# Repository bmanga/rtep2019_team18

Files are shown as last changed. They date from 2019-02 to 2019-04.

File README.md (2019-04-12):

# Gait Analysis and Interactive Training 

<p align="center">
	
</p>

### Overview
GAIT is about the development of a Raspberry Pi wearable system which analyses the user's walking characteristics and provides targeted training in two separate modes, namely Gait and Training mode.

In Gait mode, data is analysed and classified in real time by use of a deep convolutional neural network which automatically predicts the nature of the gait from the signals received from IMUs mounted on the lower limb and pressure sensors embedded in modified insoles. Training mode offers typical game-based rehabilitation exercises, including weight shifting and calf pushes, and provides both auditory and visual feedback to the user, with games being streamed to an external screen.

This device aims to promote neuroplasticity for motor rehabilitation of stroke patients and may therefore become an auxiliary tool in the recovery of motor functions of stroke survivors. 

Learn more about GAIT on the [Wiki](https://github.com/bmanga/rtep2019_team18/wiki). 

<p align="center">
	
</p>

### Prerequisites
* [conan](https://conan.io/) package manager - it can be installed by running ```pip install conan```
  * Make sure you have added the bincrafters remote repository. If not, run:<br/>
 ```conan remote add bincrafters https://api.bintray.com/conan/bincrafters/public-conan```
* [cmake](https://cmake.org/) build system version 3.8 or above

### Build Instructions
From within the cloned repository directory :
* ```mkdir build && cd build```
* ```conan install ..```
* ``` cmake ..```
* ```make```

Or use your favourite ```cmake``` configuration.

### Contributions Guidelines
All code is formatted through `clang-format` according to the `.clang-format` file. `clang-format-6.0` is the recommended version as that's the one used in CI.

The utility script `utils/format_diff_code.sh` (to be run from project root directory) is provided in order to automatically format the changes.

Alternatively, you can copy `utils/pre-commit` into the `.git/hooks` folder to automatically run `clang-format` on commits.

### Follow us!

* [Website](https://gaituofg.wixsite.com/website/)
* [Facebook](https://www.facebook.com/GaitUofG/?modal=admin_todo_tour/) 
* [Twitter](https://twitter.com/GaitUofG/) 
* [Instagram](https://www.instagram.com/gait_uofg/) 
* [YouTube](https://www.youtube.com/channel/UCVHNSSwxwb6042Gx61-woFg/)

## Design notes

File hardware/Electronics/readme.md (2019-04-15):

The Electronics folder contains the EAGLE files and data sheets for the IMU PCB and Raspberry Pi Integration Board. Each board is contained within its own folder which also contains images of the PCB's manufactured for our system.

The PCB schematic and EAGLE files conatained in this folder are as follows:
<dl>
  <b>IMU</b>
  <ul>
  <li>Board Schematic</li>
  <li>Board Layout</li>
</ul>
</dl>
<dl>
 <b>Integration Board</b>
  <ul>
  <li>Integration Board Schematic</li>
  <li>Integration Board Layout</li>
</ul>
</dl>

A description of each of these components and relative illustrations can be found in the [Wiki](https://github.com/bmanga/rtep2019_team18/wiki).

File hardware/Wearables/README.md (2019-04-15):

The Wearables folder contains the .stl files and technical drawings of the mechanical components of the device. The .stl format can be directly used for 3D printing and computer-aided manufacturing, while the technical drawings illustrate the dimensions of each part codified in ISO standards. These are grouped into two subfolders: IMU Case and RPI Box. 

A separate .stl file exists for every part component, while these are grouped together in the technical drawings. The components of the IMU Case and of the RPI box are as follows:

<dl>
  <b>IMU Case</b>
  <ul>
  <li>Top component</li>
  <li>Bottom component</li>
</ul>
</dl>
<dl>
 <b>RPI Box</b>
  <ul>
  <li>Base</li>
  <li>Cover</li>
  <li>Support</li>
  <li>Hook</li>
</ul>
</dl>

A description of each of these components and relative illustrations can be found in the [Wiki](https://github.com/bmanga/rtep2019_team18/wiki).

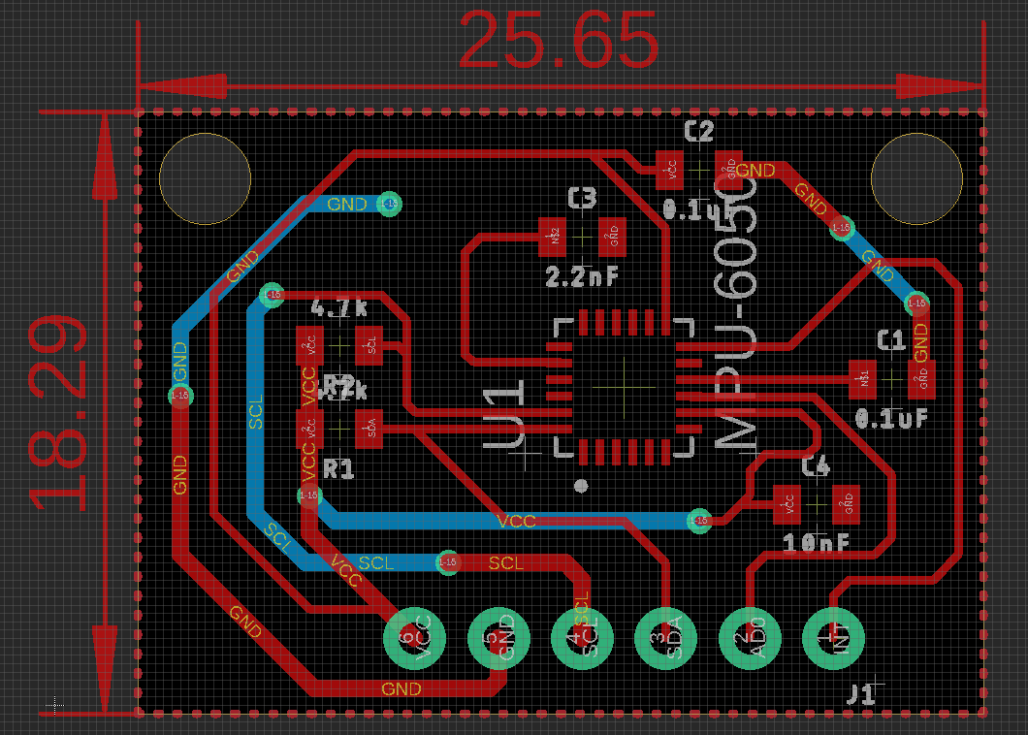
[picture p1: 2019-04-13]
hardware/Electronics/IMU/IMU Board Layout.PNG

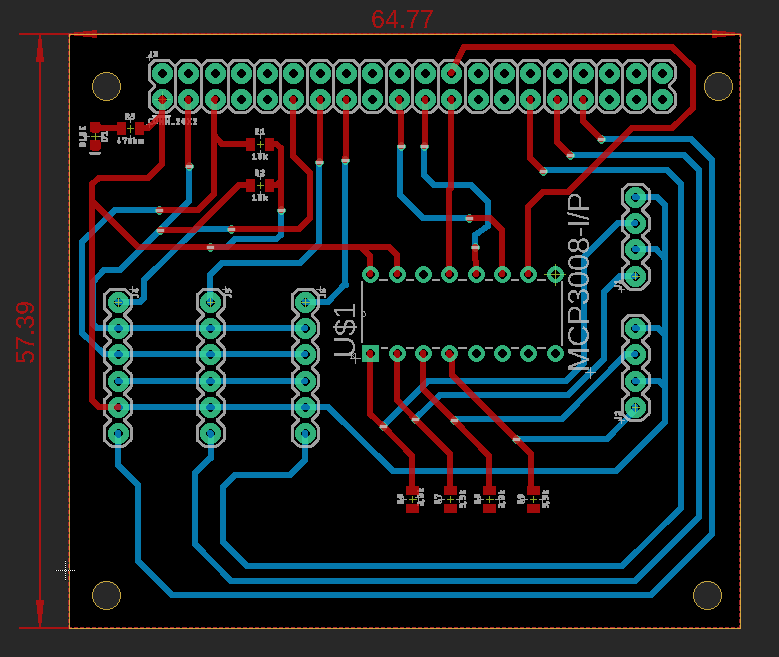
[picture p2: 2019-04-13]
hardware/Electronics/Integration Board/Eagle Files/Integration Board Layout.PNG

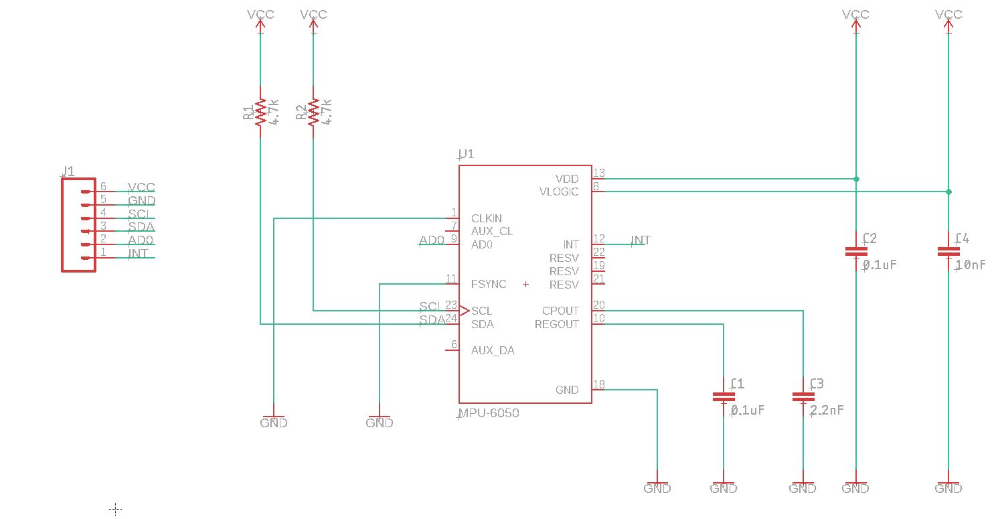
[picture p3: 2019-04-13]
hardware/Electronics/IMU/IMU Board Schematic.PNG

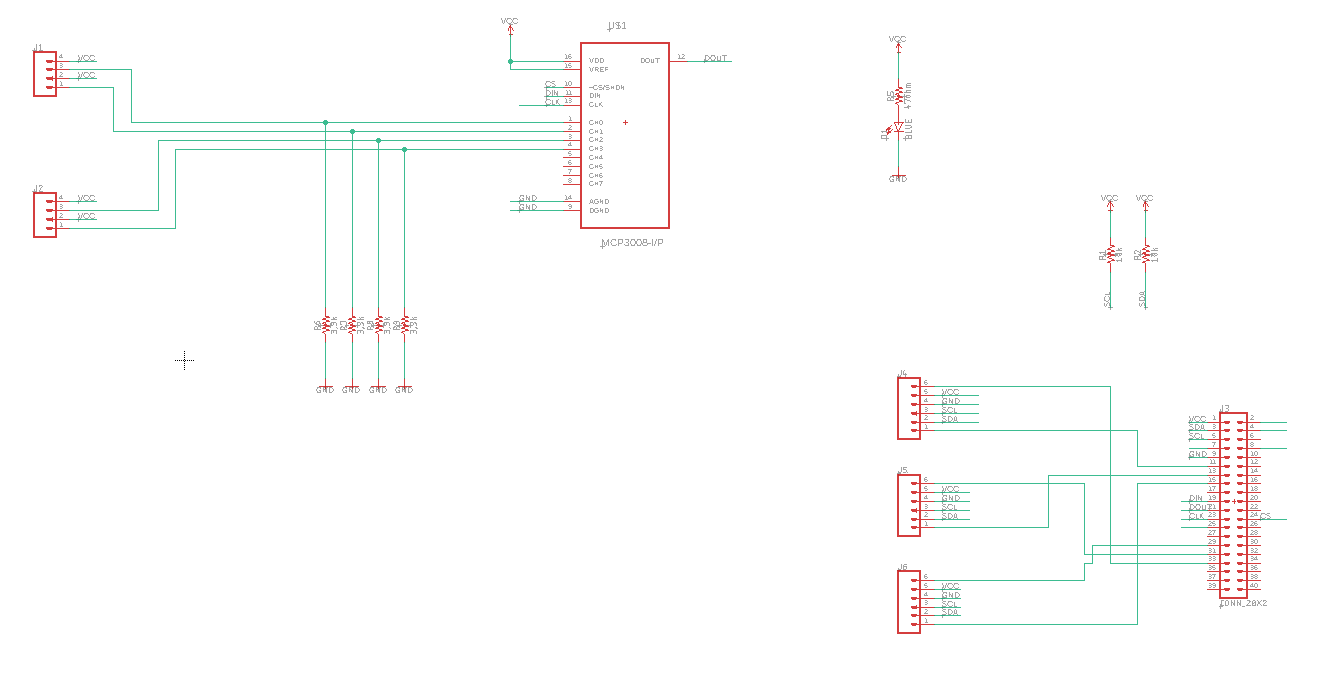
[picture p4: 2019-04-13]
hardware/Electronics/Integration Board/Eagle Files/Integration Board Schematic.PNG

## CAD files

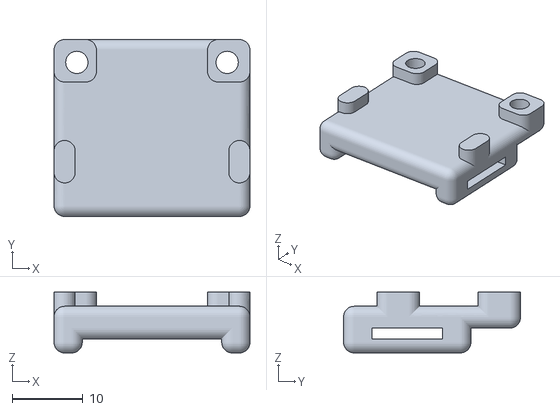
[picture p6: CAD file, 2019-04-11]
hardware/Wearables/IMU case/STL files/Bottom part.stl
27.7 x 25.0 x 8.60

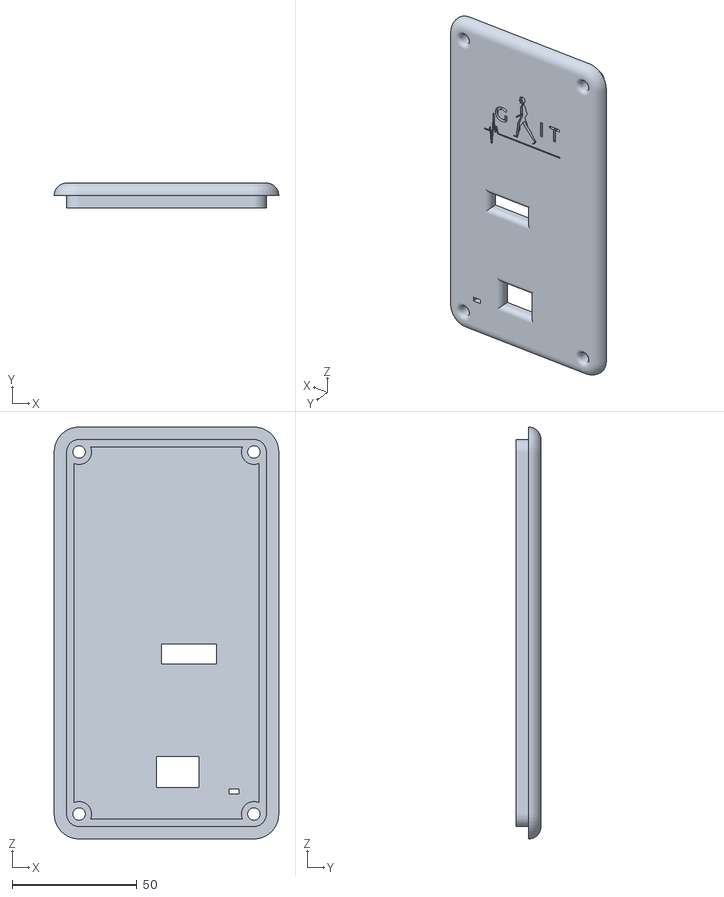
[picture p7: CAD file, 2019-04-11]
hardware/Wearables/RPI box/STL files/Top.STL
90.0 x 10.0 x 165.0

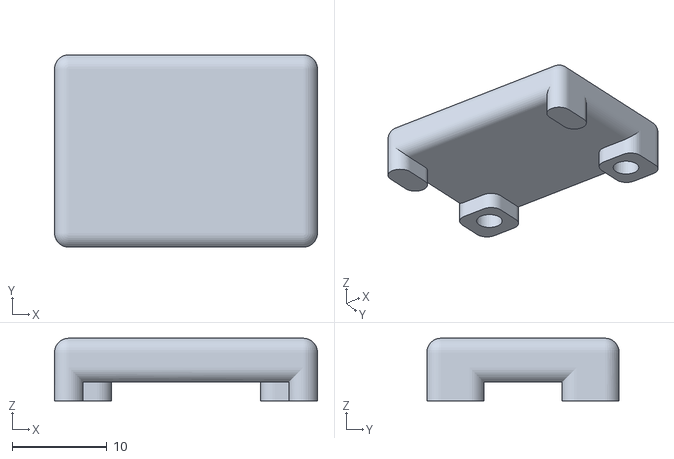
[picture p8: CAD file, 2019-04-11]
hardware/Wearables/IMU case/STL files/Top part.stl
27.7 x 20.3 x 6.60

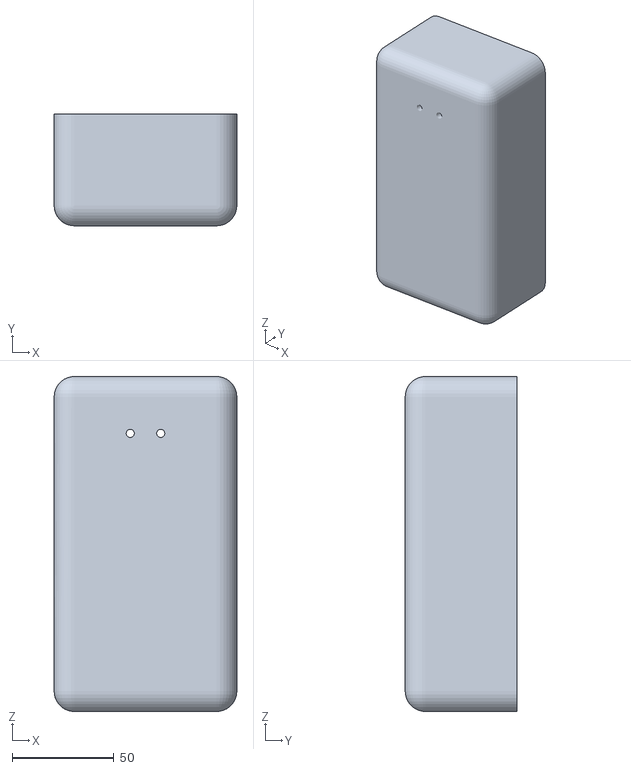
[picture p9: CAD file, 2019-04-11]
hardware/Wearables/RPI box/STL files/Base.STL
90.0 x 55.0 x 165.0

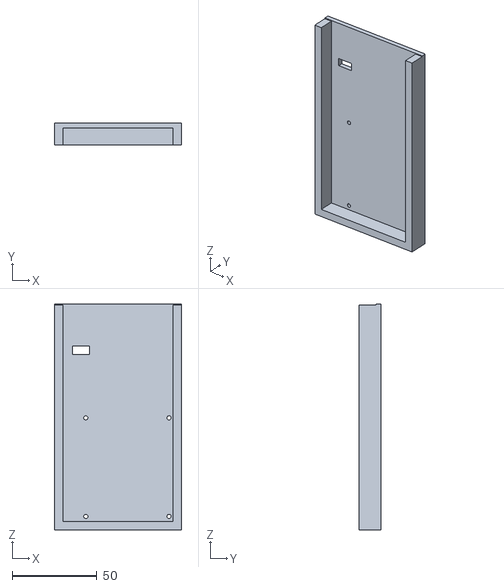
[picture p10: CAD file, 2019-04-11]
hardware/Wearables/RPI box/STL files/Middle.STL
75.0 x 13.0 x 133.0

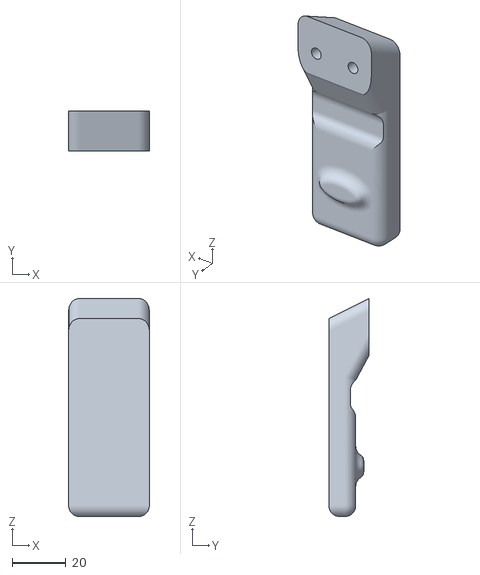
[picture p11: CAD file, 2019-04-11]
hardware/Wearables/RPI box/STL files/Hook.STL
30.0 x 15.0 x 81.1

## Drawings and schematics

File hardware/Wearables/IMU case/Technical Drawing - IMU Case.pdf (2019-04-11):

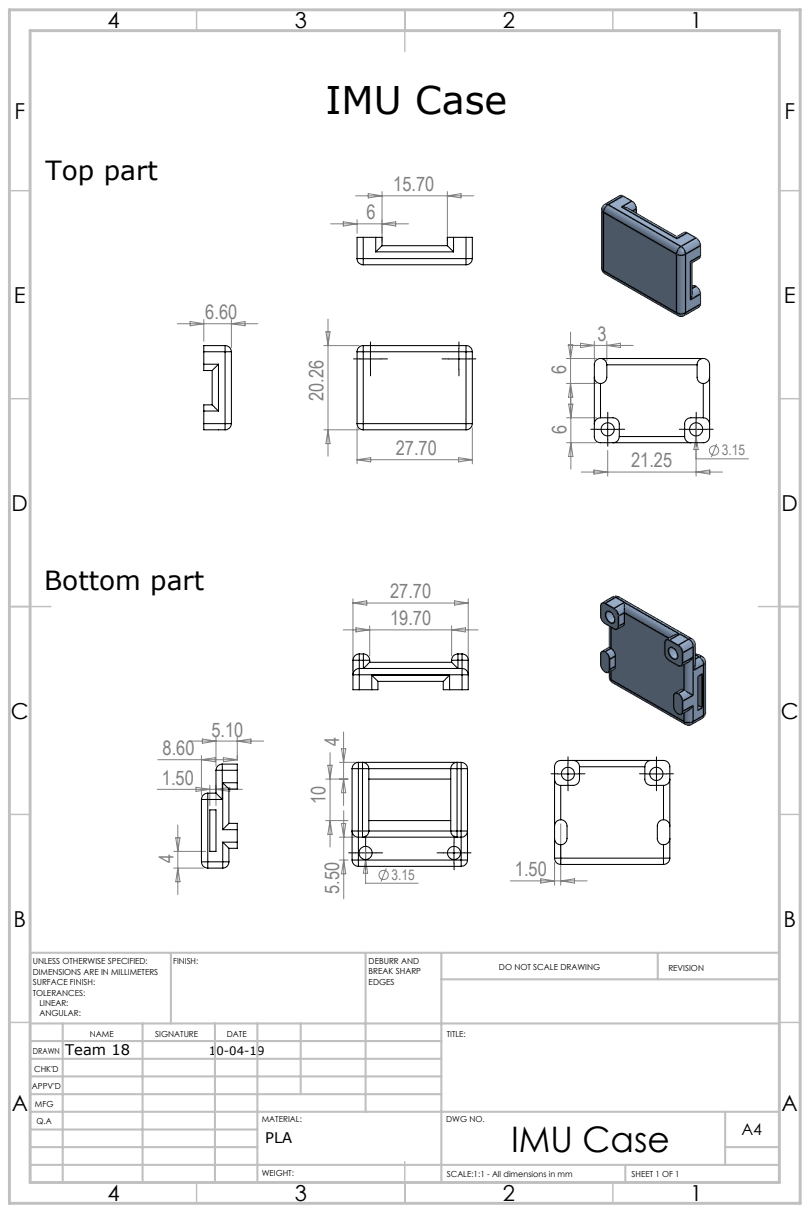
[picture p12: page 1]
IMU Case; Bottom part; Top part; FINISH:; DEBURR AND; BREAK SHARP; DO NOT SCALE DRAWING; REVISION; SCALE:1:1 - All dimensions in mm; SHEET 1 OF 1

UNLESS OTHERWISE SPECIFIED:
DIMENSIONS ARE IN MILLIMETERS
SURFACE FINISH:
TOLERANCES:
LINEAR:
ANGULAR:

NAME | SIGNATURE | DATE | | | | TITLE:

DRAWN | Team 18 | 10-04-19

CHK'D
APPV'D
MFG
Q.A | | | | MATERIAL: PLA | DWG NO. IMU Case | A4

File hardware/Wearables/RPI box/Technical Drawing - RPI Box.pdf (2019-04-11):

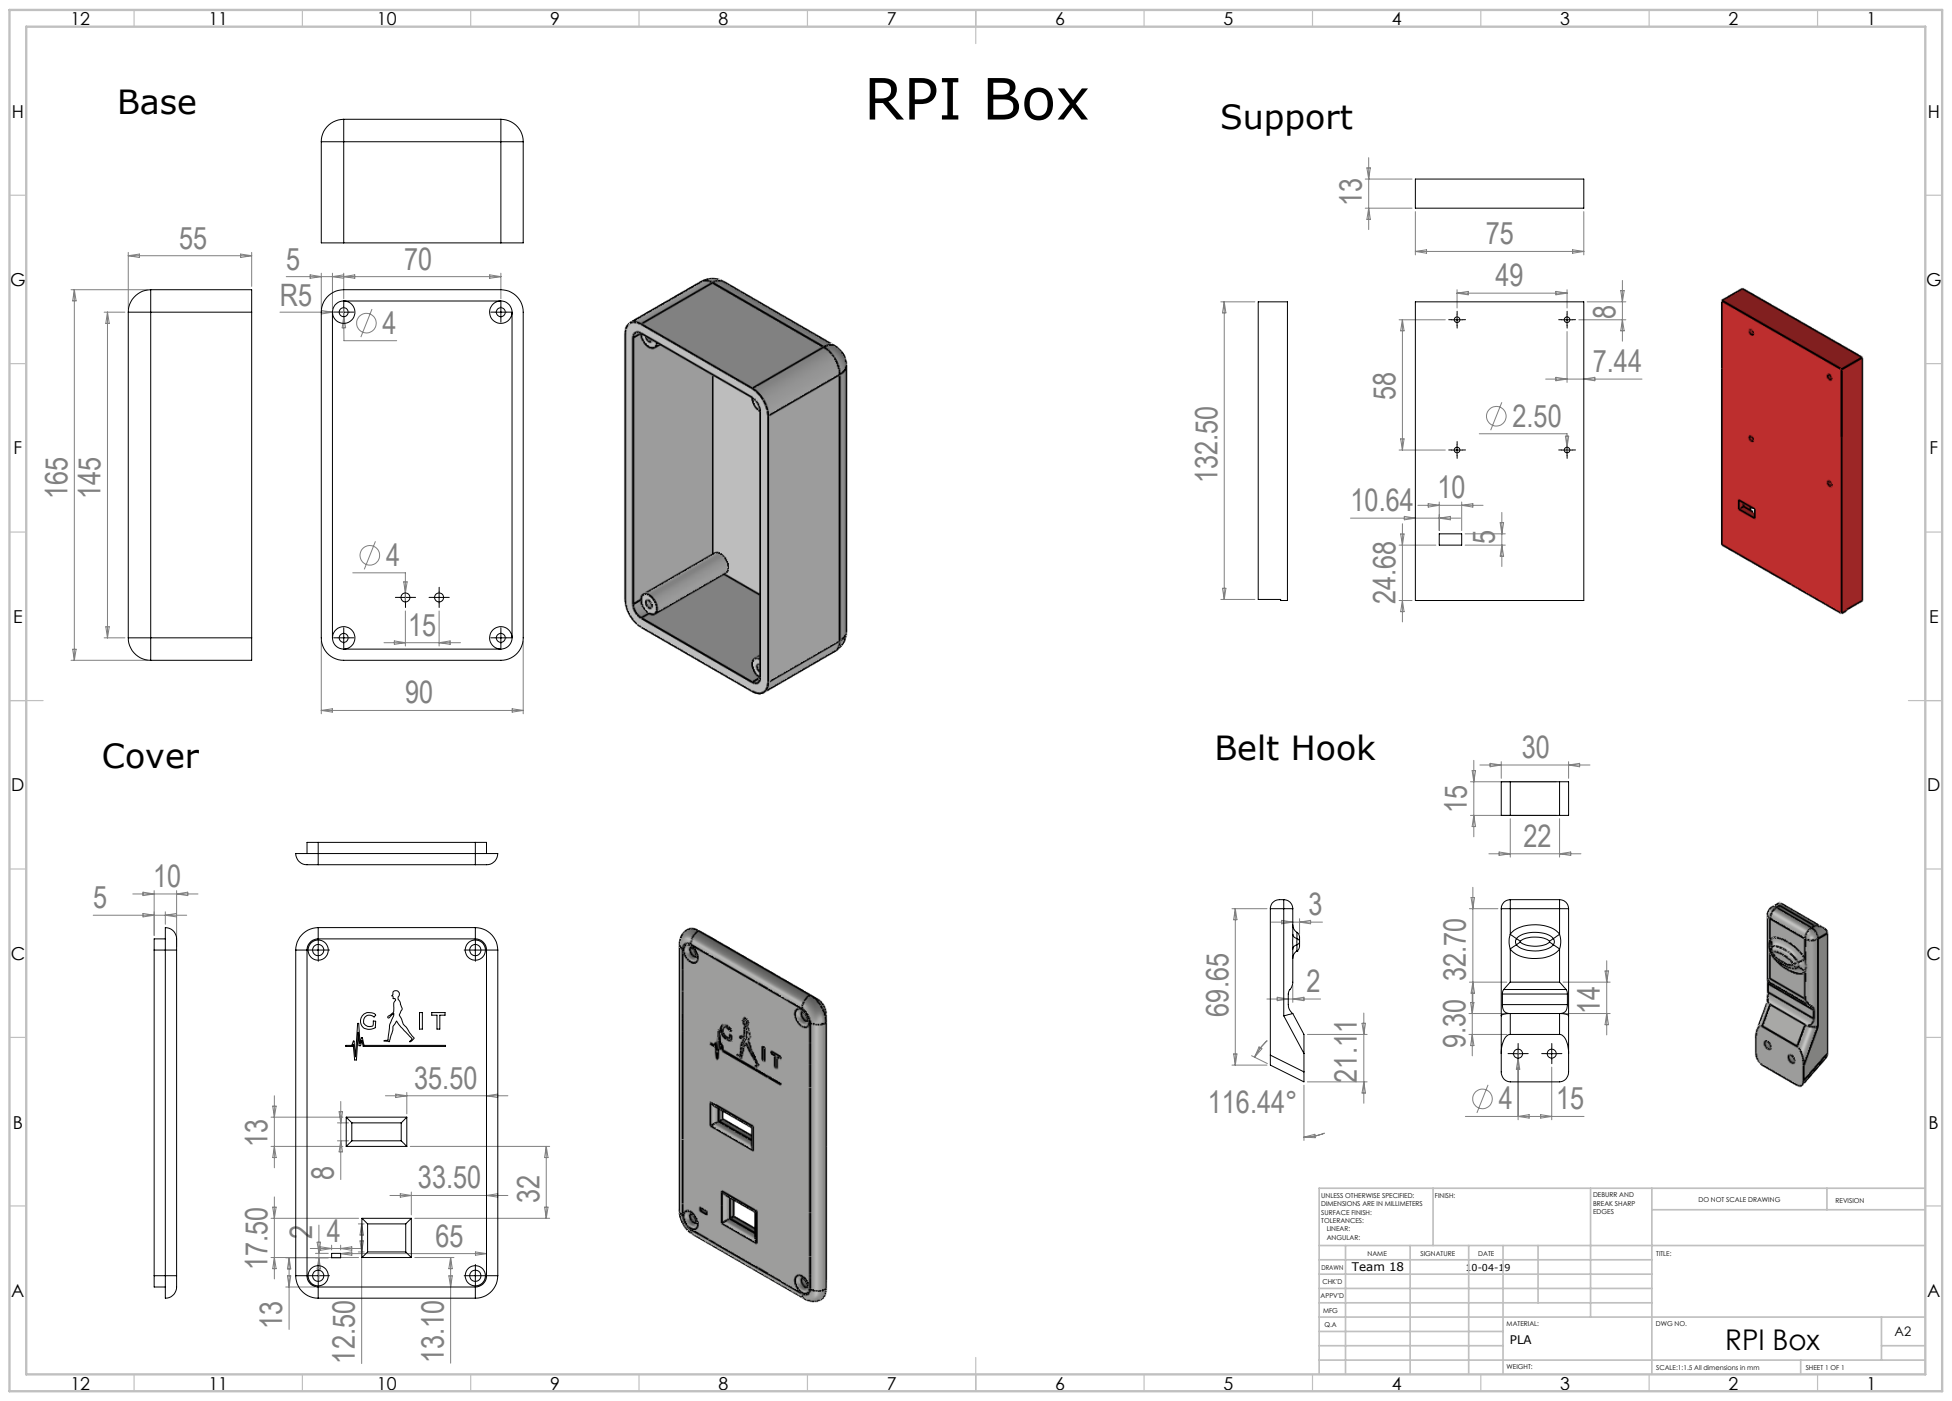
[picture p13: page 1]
Base; RPI Box; Support; Cover; Belt Hook; SCALE:1:1.5 All dimensions in mm; SHEET 1 OF 1

UNLESS OTHERWISE SPECIFIED: DIMENSIONS ARE IN MILLIMETERS SURFACE FINISH: TOLERANCES: LINEAR: ANGULAR: | FINISH: | DEBURR AND BREAK SHARP EDGES | DO NOT SCALE DRAWING | REVISION

NAME | SIGNATURE | DATE | | | | TITLE:

DRAWN | Team 18 | 10-04-19

CHK'D
APPV'D
MFG
Q.A | | | | MATERIAL: PLA | DWG NO. RPI Box | A2

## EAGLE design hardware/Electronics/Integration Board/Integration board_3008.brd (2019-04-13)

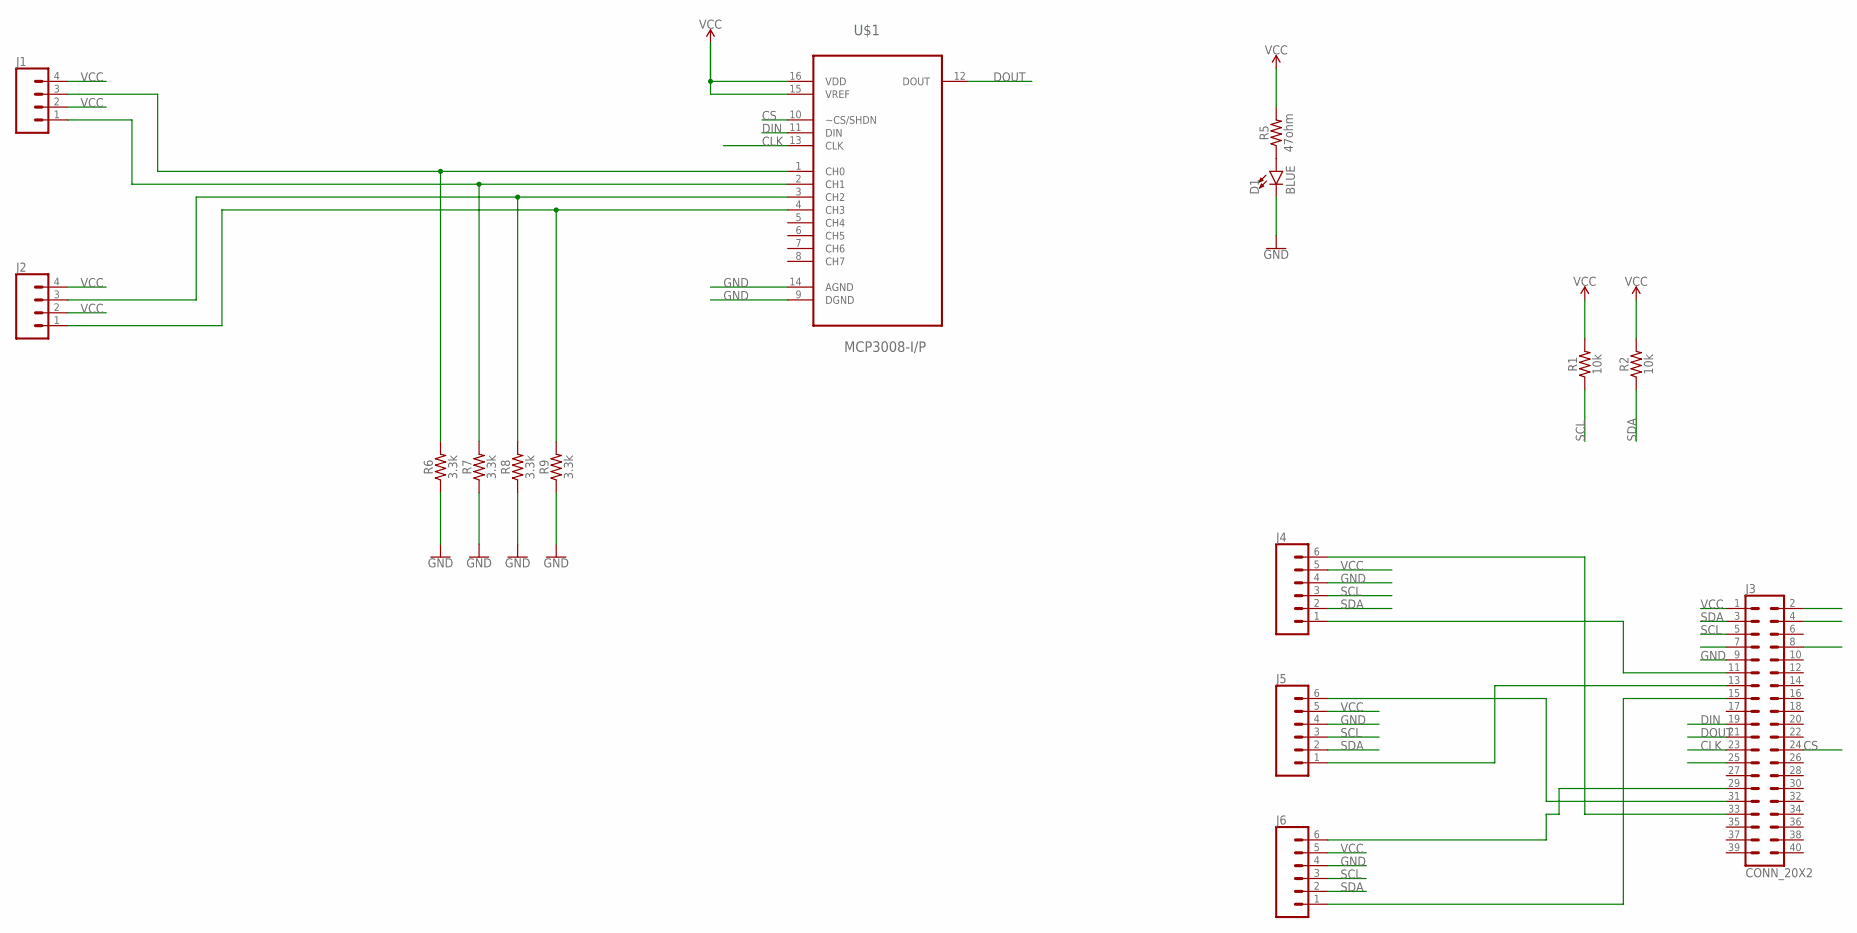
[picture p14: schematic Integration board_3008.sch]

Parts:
D1: BLUE; LED-0603
J1, J2: CONN_04PTH; 1X04
J3: CONN_20X2; 2X20
J4, J5, J6: CONN_06SILK_FEMALE_PTH; 1X06
R1, R2: 10k; 0805
R5: 47ohm; 0805
R6, R7, R8, R9: 3.3k; 0805
U$1: MCP3008-I/P; DIP254P762X432-16

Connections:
CLK: J3.23, U$1.13 (CLK)
CS: J3.24, U$1.10 (~CS/SHDN)
DIN: J3.19, U$1.11 (DIN)
DOUT: J3.21, U$1.12 (DOUT)
GND: D1.C, J3.9, J4.4, J5.4, J6.4, R6.1, R7.1, R8.1, R9.1, U$1.9 (DGND), U$1.14 (AGND)
unnamed: J1.3, R6.2, U$1.1 (CH0)
unnamed: J3.11, J4.1
unnamed: J2.3, R8.2, U$1.3 (CH2)
unnamed: J2.1, R9.2, U$1.4 (CH3)
unnamed: J3.13, J5.1
unnamed: J3.29, J6.6
unnamed: J3.31, J5.6
unnamed: D1.A, R5.1
unnamed: J1.1, R7.2, U$1.2 (CH1)
unnamed: J3.33, J4.6
unnamed: J3.15, J6.1
SCL: J3.5, J4.3, J5.3, J6.3, R1.1
SDA: J3.3, J4.2, J5.2, J6.2, R2.1
VCC: J1.2, J1.4, J2.2, J2.4, J3.1, J4.5, J5.5, J6.5, R1.2, R2.2, R5.2, U$1.15 (VREF), U$1.16 (VDD)

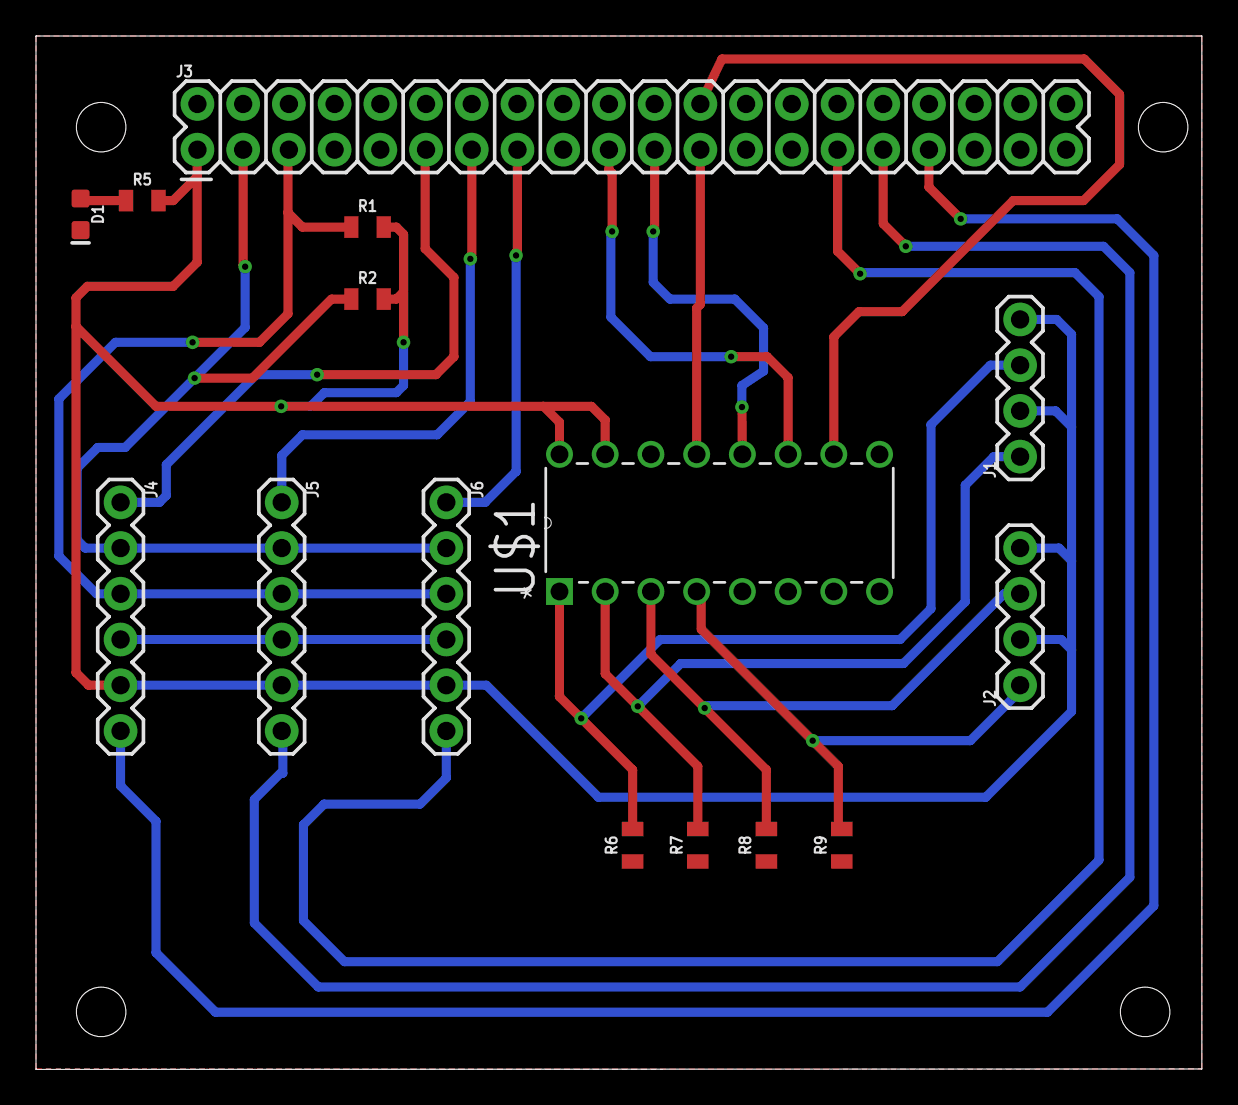
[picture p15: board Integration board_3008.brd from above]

Board: 2 copper layers, 64.8 x 57.4 mm, 15 parts (0 on the bottom side), 19 nets.

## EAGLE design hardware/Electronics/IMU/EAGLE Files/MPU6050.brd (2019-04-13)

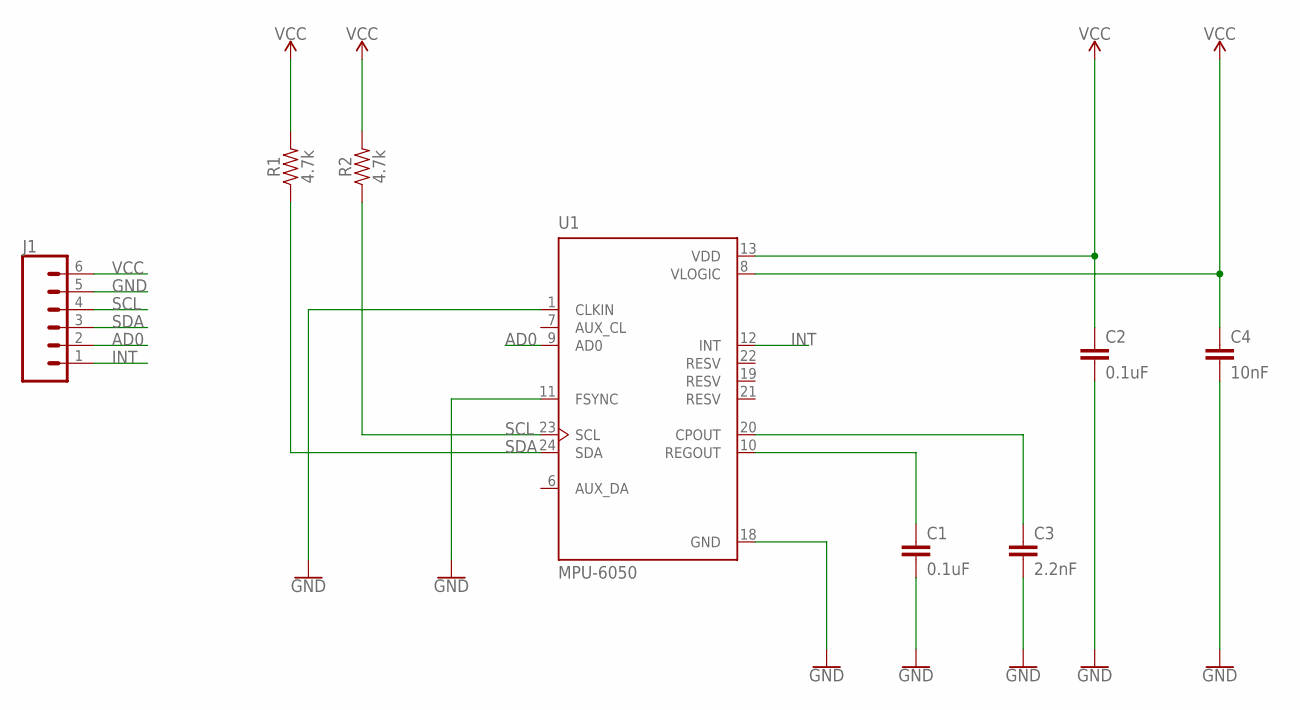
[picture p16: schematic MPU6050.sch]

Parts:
C1, C2: 0.1uF; 0805
C3: 2.2nF; 0805
C4: 10nF; 0805
J1: CONN_06NO_SILK_FEMALE_PTH; 1X06_NO_SILK
R1, R2: 4.7k; 0805
U1: MPU-6050; QFN50P400X400X95-24N

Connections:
AD0: J1.2, U1.9 (AD0)
GND: C1.2, C2.2, C3.2, C4.2, J1.5, U1.1 (CLKIN), U1.11 (FSYNC), U1.18 (GND)
INT: J1.1, U1.12 (INT)
unnamed: C1.1, U1.10 (REGOUT)
unnamed: C3.1, U1.20 (CPOUT)
SCL: J1.4, R2.1, U1.23 (SCL)
SDA: J1.3, R1.1, U1.24 (SDA)
VCC: C2.1, C4.1, J1.6, R1.2, R2.2, U1.8 (VLOGIC), U1.13 (VDD)

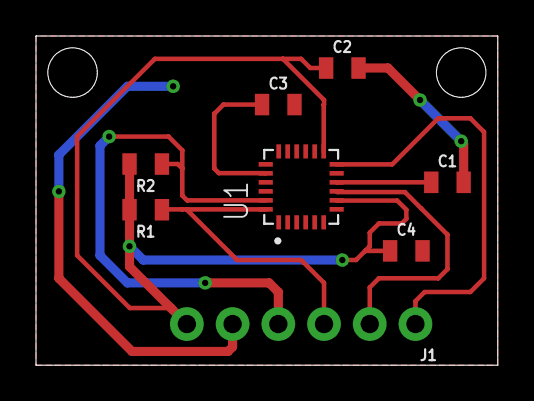
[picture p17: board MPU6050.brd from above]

Board: 2 copper layers, 25.7 x 18.3 mm, 8 parts (0 on the bottom side), 8 nets.

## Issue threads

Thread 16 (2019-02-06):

Vibrating motor evaluation

lucaros95, 2019-02-06:

bmanga, 2019-04-01:
No longer required: we don't use the motors as feedback anymore.

Closed 2019-04-01.

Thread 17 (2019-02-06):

Create the prototype shoe

lucaros95, 2019-02-06:

lucaros95, 2019-03-06:
Force distribution to avoid saturation achieved

Closed 2019-04-01.

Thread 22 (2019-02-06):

Connect IMUs to raspberry pi

lucaros95, 2019-02-06:

bmanga, 2019-02-11:
Things to consider:

- Do we want an application/library or a kernel driver?

- Data will need to be accessed by a remote computer for training and a visualization GUI (can use websockets)

- Interrupt or poll driven?

bmanga, 2019-02-12:
Going for library using wiringPi for now. Can use a kernel driver later.

Poll driven through timers.

Closed 2019-02-13.

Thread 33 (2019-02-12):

Move the IMU gathering code to be a kernel driver

bmanga, 2019-02-12:
Replace the current architecture with a kernel driver. See #22 .

bmanga, 2019-04-01:
Not much point in this. Close for now.

Closed 2019-04-01.

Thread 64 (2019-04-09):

Fix interpolation of colors

bmanga, 2019-04-09:
Currently we interpolate from the middle of the target area. This doesn't look very nice.
We should interpolate the colors from the extremities of the bars to the limits of the target area.

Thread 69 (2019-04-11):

cleanup compilation warnings

bmanga, 2019-04-11:
Currently the compilation is not clean, we get error re. deprecated qt functions and implicit `free` and `malloc` declarations.

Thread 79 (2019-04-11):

Assessment of real time responsiveness

lucaros95, 2019-04-11:
Check assessment sheet

lucaros95, 2019-04-12:
Added real-time requirements based on literature review.
Missing: How this is addressed at a software level (number of threads, etc.)

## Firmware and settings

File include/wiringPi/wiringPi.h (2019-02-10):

/*
 * wiringPi.h:
 *	Arduino like Wiring library for the Raspberry Pi.
 *	Copyright (c) 2012-2017 Gordon Henderson
 ***********************************************************************
 * This file is part of wiringPi:
 *	https://projects.drogon.net/raspberry-pi/wiringpi/
 *
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
 *    You should have received a copy of the GNU Lesser General Public License
 *    along with wiringPi.  If not, see <http://www.gnu.org/licenses/>.
 ***********************************************************************
 */

#ifndef __WIRING_PI_H__
#define __WIRING_PI_H__

// C doesn't have true/false by default and I can never remember which
//	way round they are, so ...
//	(and yes, I know about stdbool.h but I like capitals for these and I'm old)

#ifndef TRUE
#define TRUE (1 == 1)
#define FALSE (!TRUE)
#endif

// GCC warning suppressor

#define UNU __attribute__((unused))

// Mask for the bottom 64 pins which belong to the Raspberry Pi
//	The others are available for the other devices

#define PI_GPIO_MASK (0xFFFFFFC0)

// Handy defines

// wiringPi modes

#define WPI_MODE_PINS 0
#define WPI_MODE_GPIO 1
#define WPI_MODE_GPIO_SYS 2
#define WPI_MODE_PHYS 3
#define WPI_MODE_PIFACE 4
#define WPI_MODE_UNINITIALISED -1

// Pin modes

#define INPUT 0
#define OUTPUT 1
#define PWM_OUTPUT 2
#define GPIO_CLOCK 3
#define SOFT_PWM_OUTPUT 4
#define SOFT_TONE_OUTPUT 5
#define PWM_TONE_OUTPUT 6

#define LOW 0
#define HIGH 1

// Pull up/down/none

#define PUD_OFF 0
#define PUD_DOWN 1
#define PUD_UP 2

// PWM

#define PWM_MODE_MS 0
#define PWM_MODE_BAL 1

// Interrupt levels

#define INT_EDGE_SETUP 0
#define INT_EDGE_FALLING 1
#define INT_EDGE_RISING 2
#define INT_EDGE_BOTH 3

// Pi model types and version numbers
//	Intended for the GPIO program Use at your own risk.

#define PI_MODEL_A 0
#define PI_MODEL_B 1
#define PI_MODEL_AP 2
#define PI_MODEL_BP 3
#define PI_MODEL_2 4
#define PI_ALPHA 5
#define PI_MODEL_CM 6
#define PI_MODEL_07 7
#define PI_MODEL_3 8
#define PI_MODEL_ZERO 9
#define PI_MODEL_CM3 10
#define PI_MODEL_ZERO_W 12
#define PI_MODEL_3P 13

#define PI_VERSION_1 0
#define PI_VERSION_1_1 1
#define PI_VERSION_1_2 2
#define PI_VERSION_2 3

#define PI_MAKER_SONY 0
#define PI_MAKER_EGOMAN 1
#define PI_MAKER_EMBEST 2
#define PI_MAKER_UNKNOWN 3

extern const char *piModelNames[16];
extern const char *piRevisionNames[16];
extern const char *piMakerNames[16];
extern const int piMemorySize[8];

//	Intended for the GPIO program Use at your own risk.

// Threads

#define PI_THREAD(X) void *X(UNU void *dummy)

// Failure modes

#define WPI_FATAL (1 == 1)
#define WPI_ALMOST (1 == 2)

// wiringPiNodeStruct:
//	This describes additional device nodes in the extended wiringPi
//	2.0 scheme of things.
//	It's a simple linked list for now, but will hopefully migrate to
//	a binary tree for efficiency reasons - but then again, the chances
//	of more than 1 or 2 devices being added are fairly slim, so who
//	knows....

struct wiringPiNodeStruct {
  int pinBase;
  int pinMax;

  int fd;              // Node specific
  unsigned int data0;  //  ditto
  unsigned int data1;  //  ditto
  unsigned int data2;  //  ditto
  unsigned int data3;  //  ditto

  void (*pinMode)(struct wiringPiNodeStruct *node, int pin, int mode);
  void (*pullUpDnControl)(struct wiringPiNodeStruct *node, int pin, int mode);
  int (*digitalRead)(struct wiringPiNodeStruct *node, int pin);
  // unsigned int    (*digitalRead8)     (struct wiringPiNodeStruct *node, int
  // pin) ;
  void (*digitalWrite)(struct wiringPiNodeStruct *node, int pin, int value);
  //         void   (*digitalWrite8)    (struct wiringPiNodeStruct *node, int
  //         pin, int value) ;
  void (*pwmWrite)(struct wiringPiNodeStruct *node, int pin, int value);
  int (*analogRead)(struct wiringPiNodeStruct *node, int pin);
  void (*analogWrite)(struct wiringPiNodeStruct *node, int pin, int value);

  struct wiringPiNodeStruct *next;
};

extern struct wiringPiNodeStruct *wiringPiNodes;

// Export variables for the hardware pointers

extern volatile unsigned int *_wiringPiGpio;
extern volatile unsigned int *_wiringPiPwm;
extern volatile unsigned int *_wiringPiClk;
extern volatile unsigned int *_wiringPiPads;
extern volatile unsigned int *_wiringPiTimer;
extern volatile unsigned int *_wiringPiTimerIrqRaw;

// Function prototypes
//	c++ wrappers thanks to a comment by Nick Lott
//	(and others on the Raspberry Pi forums)

#ifdef __cplusplus
extern "C" {
#endif

// Data

// Internal

extern int wiringPiFailure(int fatal, const char *message, ...);

// Core wiringPi functions

extern struct wiringPiNodeStruct *wiringPiFindNode(int pin);
extern struct wiringPiNodeStruct *wiringPiNewNode(int pinBase, int numPins);

extern void wiringPiVersion(int *major, int *minor);
extern int wiringPiSetup(void);
extern int wiringPiSetupSys(void);
extern int wiringPiSetupGpio(void);
extern int wiringPiSetupPhys(void);

extern void pinModeAlt(int pin, int mode);
extern void pinMode(int pin, int mode);
extern void pullUpDnControl(int pin, int pud);
extern int digitalRead(int pin);
extern void digitalWrite(int pin, int value);
extern unsigned int digitalRead8(int pin);
extern void digitalWrite8(int pin, int value);
extern void pwmWrite(int pin, int value);
extern int analogRead(int pin);
extern void analogWrite(int pin, int value);

// PiFace specifics
//	(Deprecated)

extern int wiringPiSetupPiFace(void);
extern int wiringPiSetupPiFaceForGpioProg(
    void);  // Don't use this - for gpio program only

// On-Board Raspberry Pi hardware specific stuff

extern int piGpioLayout(void);
extern int piBoardRev(void);  // Deprecated
extern void piBoardId(int *model,
                      int *rev,
                      int *mem,
                      int *maker,
                      int *overVolted);
extern int wpiPinToGpio(int wpiPin);
extern int physPinToGpio(int physPin);
extern void setPadDrive(int group, int value);
extern int getAlt(int pin);
extern void pwmToneWrite(int pin, int freq);
extern void pwmSetMode(int mode);
extern void pwmSetRange(unsigned int range);
extern void pwmSetClock(int divisor);
extern void gpioClockSet(int pin, int freq);
extern unsigned int digitalReadByte(void);
extern unsigned int digitalReadByte2(void);
extern void digitalWriteByte(int value);
extern void digitalWriteByte2(int value);

// Interrupts
//	(Also Pi hardware specific)

extern int waitForInterrupt(int pin, int mS);
extern int wiringPiISR(int pin, int mode, void (*function)(void));

// Threads

extern int piThreadCreate(void *(*fn)(void *));
extern void piLock(int key);
extern void piUnlock(int key);

// Schedulling priority

extern int piHiPri(const int pri);

// Extras from arduino land

extern void delay(unsigned int howLong);
extern void delayMicroseconds(unsigned int howLong);
extern unsigned int millis(void);
extern unsigned int micros(void);

#ifdef __cplusplus
}
#endif

#endif

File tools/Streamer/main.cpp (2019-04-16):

#include <chrono>
#include <iostream>
#include <thread>
#include "IMU/IMU.h"
#include "common_types.h"
#include "fsr/fsr_reader.h"
#include "telemetry/server.h"

using namespace std;

int main()
{
  tel::server server;
  server.run_on_thread(9004);

  Sensor_IMU imu_1(0);
  Sensor_IMU imu_2(2);
  Sensor_IMU imu_3(3);

  imu_1.initialize();
  imu_2.initialize();
  imu_3.initialize();

  mcp3008Spi a2d("/dev/spidev0.0", SPI_MODE_0, 1000000, 8);
  int i = 20;
  int a2dVal = 0;
  int a2dChannel = 0;
  unsigned char pdata[3];

  sensors_data data = {};

  using clk = std::chrono::steady_clock;
  auto start_time = clk::now();

  while (1) {
    pdata[0] = 1;  //  first byte transmitted -> start bit
    pdata[1] =
        0b10'000'000;  // second byte transmitted -> (SGL/DIF = 1, D2=D1=D0=0)
    pdata[2] = 0;      // third byte transmitted....don't care

    a2d.spiWriteRead(pdata, sizeof(pdata));

    a2dVal = 0;
    a2dVal = (pdata[1] << 8) &
             0b1100000000;  // merge data[1] & data[2] to get result
    a2dVal |= (pdata[2] & 0xff);

    cout << "The Result is: " << a2dVal << endl;
    data.left.heel = a2dVal / 512.0f;

    // Second
    pdata[0] = 1;  //  first byte transmitted -> start bit
    pdata[1] =
        0b10'010'000;  // second byte transmitted -> (SGL/DIF = 1, D2=D1=D0=0)
    pdata[2] = 0;      // third byte transmitted....don't care

    a2d.spiWriteRead(pdata, sizeof(pdata));

    a2dVal = 0;
    a2dVal = (pdata[1] << 8) &
             0b1100000000;  // merge data[1] & data[2] to get result
    a2dVal |= (pdata[2] & 0xff);

    cout << "The Result is: " << a2dVal << endl;
    data.left.toe = a2dVal / 512.0f;

    // Third
    pdata[0] = 1;  //  first byte transmitted -> start bit
    pdata[1] =
        0b10'100'000;  // second byte transmitted -> (SGL/DIF = 1, D2=D1=D0=0)
    pdata[2] = 0;      // third byte transmitted....don't care

    a2d.spiWriteRead(pdata, sizeof(pdata));

    a2dVal = 0;
    a2dVal = (pdata[1] << 8) &
             0b1100000000;  // merge data[1] & data[2] to get result
    a2dVal |= (pdata[2] & 0xff);

    cout << "The Result is: " << a2dVal << endl;
    data.right.heel = a2dVal / 512.0f;

    // Fourth
    pdata[0] = 1;  //  first byte transmitted -> start bit
    pdata[1] =
        0b10'110'000;  // second byte transmitted -> (SGL/DIF = 1, D2=D1=D0=0)
    pdata[2] = 0;      // third byte transmitted....don't care

    a2d.spiWriteRead(pdata, sizeof(pdata));

    a2dVal = 0;
    a2dVal = (pdata[1] << 8) &
             0b1100000000;  // merge data[1] & data[2] to get result
    a2dVal |= (pdata[2] & 0xff);

    cout << "The Result is: " << a2dVal << endl;
    data.right.toe = a2dVal / 512.0f;

    data.a.ax = imu_1.getAccel_X() / 16384.0;
    data.a.ay = imu_1.getAccel_Y() / 16384.0;
    data.a.az = imu_1.getAccel_Z() / 16384.0;
    data.a.gx = imu_1.getGyro_X() / 16384.0;
    data.a.gy = imu_1.getGyro_Y() / 16384.0;
    data.a.gz = imu_1.getGyro_Z() / 16384.0;

    data.b.ax = imu_2.getAccel_X() / 16384.0;
    data.b.ay = imu_2.getAccel_Y() / 16384.0;
    data.b.az = imu_2.getAccel_Z() / 16384.0;
    data.b.gx = imu_2.getGyro_X() / 16384.0;
    data.b.gy = imu_2.getGyro_Y() / 16384.0;
    data.b.gz = imu_2.getGyro_Z() / 16384.0;

    data.c.ax = imu_3.getAccel_X() / 16384.0;
    data.c.ay = imu_3.getAccel_Y() / 16384.0;
    data.c.az = imu_3.getAccel_Z() / 16384.0;
    data.c.gx = imu_3.getGyro_X() / 16384.0;
    data.c.gy = imu_3.getGyro_Y() / 16384.0;
    data.c.gz = imu_3.getGyro_Z() / 16384.0;

    float elapsed_s = std::chrono::duration_cast<std::chrono::milliseconds>(
                          clk::now() - start_time)
                          .count() /
                      1000.f;

    data.timepoint = elapsed_s;
    std::this_thread::sleep_for(std::chrono::milliseconds(25));
    server.broadcast(&data, sizeof(data));
  }
}

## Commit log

2019-01-23 Update README.md
    Add current build requirements and simple building steps
2019-02-10 wiringPi: add minimal wiringPi library for i2c comms
2019-02-12 Library: Add IMU data acquisition library.
2019-02-13 tools: add IMUStreamer executable
2019-02-20 tools: add qt gui for imu visualization
2019-03-02 libimu: split fd creation from sensor constructor
2019-03-02 libimu: work with multiple sensors
2019-03-20 qt gui: added graphs for different sensors
2019-03-20 tools:update Qt to handle multiple IMUs and FSRs
2019-03-20 tools: fix line endings to unix style
    [main.cpp]
2019-03-25 lib: fix telemetry thread
2019-04-08 Uploaded IMU and integration board EAGLE files.
    [Integration board.brd, Integration board.sch, Integration board_3008.brd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]
2019-04-11 harware: reorganized folders, added wearables design files
    [Base.STL, Bottom part.stl, Hook.STL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]
2019-04-11 lib: added library to use ADC
2019-04-11 lib: split constructor fro IMU reader
2019-04-11 tools: update IMUStreamer for pretty printing and fix packet struct
    [main.cpp]
2019-04-11 tools: revert fmt requirement, because it does not play well with clang CI
    [main.cpp]
2019-04-12 hardware: include datasheets of IMU chip, FSR, and ADC
2019-04-13 Added IMU and Integration board schematic and layout PNG's
    [Integration board.brd, Integration board.sch, Integration board_3008.brd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]
2019-04-15 Edited GUI, now works with realtime data from sensors.
2019-04-15 qt gui: training mode receiving data from sensors
2019-04-15 Added calibration functionality.
2019-04-15 Fixed calibration functionality and added progress bar to calibration window.
2019-04-15 Changed sensor structs to use common_types. Fixed calibrate window done signal.
    [main.cpp]
2019-04-15 Switched saving of left and right in streamer.

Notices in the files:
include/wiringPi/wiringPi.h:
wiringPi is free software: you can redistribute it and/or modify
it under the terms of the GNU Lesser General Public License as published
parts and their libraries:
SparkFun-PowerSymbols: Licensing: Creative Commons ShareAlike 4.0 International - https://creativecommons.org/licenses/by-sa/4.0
